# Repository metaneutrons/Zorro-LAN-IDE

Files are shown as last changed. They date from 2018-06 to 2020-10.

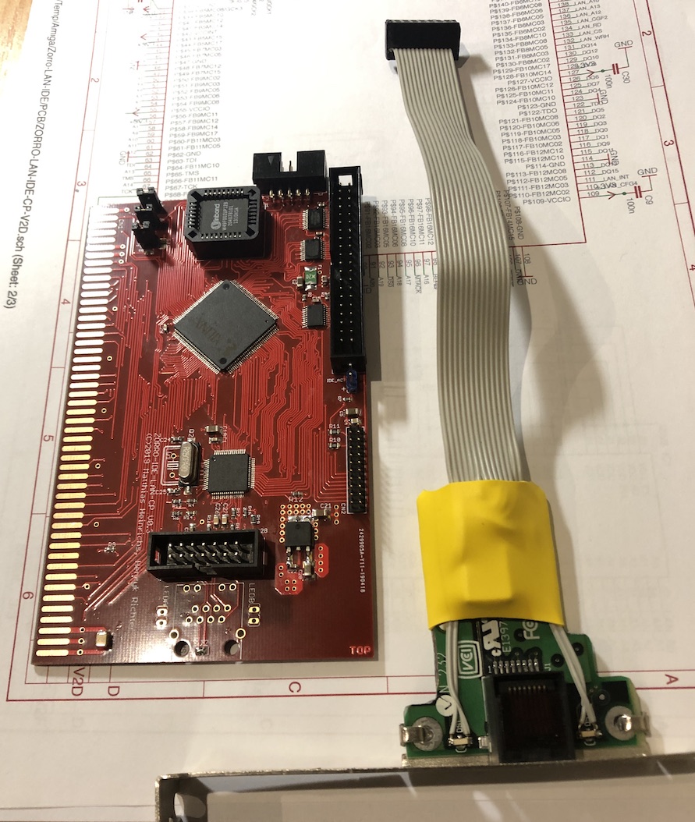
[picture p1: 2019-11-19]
Bilder/LANIDEv03.JPG

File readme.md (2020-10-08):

# Zorro-LAN-IDE
 
This is a Zorro-expansion card for the big Amigas (A2000/300/4000 or A500 with Zorro-interface). It has a SANAII-compatible Ethernet driver, an AT-BUS compatible IDE controller and a clockport for variuous expansions like a RapidRoard from Individual Computers.

Here is a pic of the first revision:
Zorro-Card with LAN-Module

All components are Autoconfig. The FastEthernet is based on a ENC624J600 lan chip. The clockport is compatible to A600/A1200 ones but resides at a different address. The IDE works from Kickstart 1.3 to 3.1.4 !

At present there are two firmwares: One for Zorro2, which runs in every Amiga with Zorro-Sots and one for A3000/4000, which puts the LAN-Chip into a Zorro3 environment. The while the Zorro2 variant can transfer 3.5mb/s at most the Zorro3-variant has a significantly faster LAN<->Amiga interface of 6-7mb/sec. Please note that these RAW data transfer numbers are not the only factor in LAN performance on Amiga and that the actual observed speeds with TCP transfers are in the range of 1-2 MB/s (depending on IP stack and CPU). 

Here is a pic of the current board revision:
Zorro-Card with onboard LAN chip

## Things to improve

* The second revision already adresses the issues of the Zorro3-incompatible IDE-Interface.
* There is no Z2/Z3 combo firmware, yet.
* The RJ45-breakout (actually it's a MagJack with build in transceiver) of the 2nd revision looks bad 

**DISCLAIMER!!!!**  
**THIS IS A HOBBYIST PROJECT! I'M NOT RESPONSIBLE IF IT DOESN'T WORK OR DESTROYS YOUR VALUABLE DATA!**

## License
All sources published under GNU GENERAL PUBLIC LICENSE V2.0

## Theory of operation
* This PCB has four layers and consists of a Xilinx XC95288XL, a bootrom and some bus bufferes for the IDE port, a clockport and a ENC624J600 including a RJ45-connector with integrated receiver. 

* The CPLD does four things:
    * It makes the Autoconfig for the IDE, the clockport and the LAN-chip
    * It adapts the LAN Chip to Zorro2/3 and does necessary byte swapping, so the Amiga can linearely access the whole chip.
    * It acesses the clockport
    * It controlls the IDE

## How to make the clockport work with a RapidRoad?

Make sure you connected the cable the right way! There is no "standarized way". So the easiest thing is to find out on the RapidRoad side on which row of the clockport the two outer pins are ground. These Pins mus run to the row of the Zorro-LAN-IDE-CP-card where the squared solder-hole is located. *Please triple check the cable with a multimeter! Wrong polarity of the cable can cause damage to your hardware!* 
Now you have to set up the driver to look for a clockport at the address of the expansion board. The address can be figured out by the system tool "ShowConfig" (Manufactor id: 2588 Product: 124). 
However, there is work on a software solution, that the RapidRoad finds itself automatically!

## What is in this repository?
This repository consists of several directories:

* Bilder: Some pictures of this project
* Doku: Some documentation and datasheets. Mainly for the ENC624J600
* Driver: Here is the driver developped by Henryk Richter
* Logic: Here the code, project files and pin-assignments for the CPLD is stored. There are two versions: 
* PCB: The board, schematic and bill of material (BOM) are in this directory. 
* root directory: the readme

## How to open the PCB-files?
You find the eagle board and schematic files (brd/sch) for the pcb. The software can be [downloaded](https://www.autodesk.com/products/eagle/overview) for free after registration. KiCad can import these files too. But importers are not 100% reliable... 

## How to make a PCB?
You can generate Gerber-files from the brd files according to the specs of your PCB-manufactor. Some specs: min trace width: 0.15mm/6mil, min trace dist: 0.15mm/6mil, min drill: 0.3mm

**ATTENTION: THE PCB has 4 layers!**

## How to get the parts?
Most parts can be found on digikey or mouser or a parts supplier of your choice.
A list of parts is found in the file [ZORRO-LAN-IDE-CP-V2E.txt](https://gitlab.com/MHeinrichs/Zorro-LAN-IDE/raw/master/PCB/ZORRO-LAN-IDE-CP-V2E.txt)

## How to programm the board?
The CPLD must be programmed via Xilinx IMPACT and an apropriate JTAG-dongle. The JED-File is provided. 

## It doesn't work! How to I get help?
For support visit the [a1k-forum](https://www.a1k.org/forum/showthread.php?t=56940). Yes, you need to register and it's German, but writing in English is accepted. For bug-reports write a ticket here ;).

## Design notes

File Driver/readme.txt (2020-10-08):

These are the AmigaOS drivers for the subsystems of the board.

The recommended SANA-II driver for the Ethernet port is located in "baxnet". 

Please use enc624j6net.device from baxnet/bin on MC68020 or faster CPUs. A cut-down version for 68000 and 68010 is provided as well. Please rename enc624j6net.device_68000 to enc624j6net.device before copying it to DEVS:Networks.

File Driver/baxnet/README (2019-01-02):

Short:        V2.00, SANA-II network drivers for several adapters 
Author:       Henryk Richter
Uploader:     henryk.richter@gmx.net
Type:         driver/net
Architecture: m68k-amigaos
Requires:     OS 2.04+

This package contains network drivers for the following hardware:
- ZII LAN IDE CP (matze, scrat and buggs @a1k.org)
  OSS Zorro-II card with ENC624J600 ethernet controller, autoboot
  IDE and Clockport
- Vampire500/600 with ENC28J60 module connected to the SD-card slot
- Vampire500V2+ with ENC28J60 module connected to the expansion port

Full source code is included. Please refer to README.sdnet and
README.enc for installation and operation instructions

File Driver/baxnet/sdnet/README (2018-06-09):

SDNet - A SANA-II driver for ENC28J60 10BaseT ethernet modules

Written in 2016-2018 by Henryk Richter <henryk.richter@gmx.net>

This driver is supposed to support ENC28J60 modules hooked up to the MicroSD
slot of Vampire 500/600 cards or the expansion port of Vampire 500V2+ cards.

Installation:
-------------

Installation of the driver is straightforward. 
Just copy the sdnet.device and v2expeth.device to devs:networks and enable 
the interface in your favorite  TCP/IP stack as usual. So far, successful 
tests have been done with the free AmiTCP/IP 3.0b2, AmiTCP4.0-4.2, Genesis, 
MiamiDX and RoadShow. 

devs:networks/sdnet.device    - SD card slot of V600/V500
devs:networks/v2expeth.device - expansion port of V500V2+

From version 0.8, the driver will require vampire.resource which is included
in the ROM of Vampire Cards since the Gold2.5 release.

Also, make sure that the Vampire SD Card driver (sagasd.device) is not present
in the system or at least inactive when using sdnet.device. Both pieces of 
software bang the same hardware registers. v2expeth.device may be used safely
in conjunction with the SD card driver.

Vampire500 Expansion port Hardware
-----------------------------------

Please see http://wiki.apollo-accelerators.com/doku.php/expansionport for 
guidance.

MicroSD Slot Hardware:
----------------------

In terms of required hardware, you need the following:
- ready-to-use ENC28J60 module (a 3.3V part, DON'T USE an _unmodified_ 5V 
  module!)
- MicroSD breakout, e.g.
  - a TF to SD extension cable where you rip off the full size SD slot and 
    solder on short extension cables towards the ENC28J60 module
  - MicroSD breakout board (that comes directly with pin headers)

!!ATTENTION!!
Be extremely careful with your SD breakout board. Many conveniently looking
breakouts are made of thick and/or sharp edged PCB material that will likely
damage your Vampire SD slot. Such breakouts could be made working - but only 
after  patient sanding. Some people in the beta test team have destroyed 
their SD  slot already. If you don't have the required mechanical skills and 
patience, I'd advise against DIY building.
!!ATTENTION!!

You need to connect the SD breakout pins as follows (microSD card sketch
looking at the connectors) to the ENC28J60 module:

 -----------------------                       ENC28J60
 |  8  ----
 |  7  ----           SO  --------------------  SO
 |  6 -----          GND  --------------------  GND
 |  5  ----          SCK  --------------------  SCK
 |  4 -----        +3.3V  ------  +3.3V  -----  VCC (see below)
 |  3  ----           SI  --------------------  SI
 |  2  ----          /CS  --------------------  /CS
 |  1  ----         /INT  --   __________   -- /INT
 ------    -------------    \_| 3.3 kOhm |_/
       \___|                  `----------´

As there is a myriad of ENC28J60 modules available, the naming scheme on
a particular board might differ. Please be aware the some of the boards
have a "CLK" pin as well as an "SCK" pin. Use the latter. 

My test setup uses a separate 5V to 3.3V DC-DC converter. I got confirmation 
from Igor Majstorovic (majsta) that the 3.3V line on his V500 Vampire designs 
should be able to handle the max. 200 mA required by the module. To be on the 
safe side, I recommend to use a conveniently placed 5V to 3.3V converter 
(hint: the Floppy power connector is easily accessible). 

Speaking of power: the reason why I didn't recommend 5V ENC28J60 boards 
is that at least some of them have pullups from /CS and /RST to +5V. Your 3.3V
Vampire SD slot will quite likely not be happy with that.

Please put a 3.3 kOhm resistor into the connection from /INT of the ENC28J60 to
pin 1 of the MicroSD breakout.

Testing a new module:
---------------------

I've included two small test programs: sdnettest and v2expethtest. Both will 
require the TCP/IP stack to be off(!) The program will perform a series of tests 
to check for module presence and communication results at various clock rates. Don't 
be alarmed when the slowest (biggest clock divider) mode is commented with a "fail". 
This is intentional. What matters is that SPI clock dividers 1, 2 and 3 are working 
properly. In case that sdnettest shows a failure for divider 1, see below how
to set a higher clock divider.

Use sdnettest for the SD slot and v2expethtest for the V500 expansion connector.

Software notes:
---------------

 - The SD slot doesn't feature an interrupt. I had to implement polling
   for incoming data. The current default interval is 10ms. (configurable via
   echo "TIMER=20000" >ENVARC:sana2/sdnet.config, value in microseconds,
   don't forget Makedir ENVARC:Sana2 if it didn't exist yet, you may also
   consider "setenv")

 - SPI speed is set to a safe level supporting higher core speeds than
   x11 (see released x12 cores). Therefore this default of "SPISPEED=2"
   is not providing maximum performance on x10 or x11 cores. For max
   speed you may set echo "SPISPEED=1" >ENVARC:sana2/sdnet.config or
   echo "SPISPEED=1" >ENVARC:sana2/v2expeth.config, respectively. I'd
   suggest to run the test tool to determine the maximum reliable
   speed setting.

 - The required vampire.resource is unavailable with older versions of the
   Vampire Kick Rom (anything before Gold2.5). 
   To load vampire.resource manually, copy the file to SYS:devs/ and 
   add the following near the top of your startup-sequence
    C:VERSION >nil: vampire.resource 42
    IF WARN
       LoadModule >nil: DEVS:vampire.resource
    ENDIF
   In case of OS3.9, you can add the "noreboot" keyword to the loadmodule
   line if you call the sniplet above before setpatch.

 - If you want to use multiple options in the SANA-II config, concatenate them 
   in the "echo" command (alternatively "setenv") or use a text editor. 

Options 
-------

Below you find the options accepted by the drivers. Please note that no special
configuration is necessary for normal operation. What you find documented below
is available for tuning purposes.

The options template for the config files 
ENVARC:sana2/sdnet.config  
ENVARC:sana2/v2expeth.config

is as follows:

NOSPECIALSTATS/S,PRIORITY=PRI/K/N,BPS/K/N,MTU/K/N,FULLDUPLEX/S,SPISPEED/K/N,
TIMER/K/N,MULTICAST/S

 SPISPEED       - SPI clock divider (1-10, default 2), controls maximum
                  clock of SPI bus. Actual I/O clock is Core_Clock/(3+SPISPEED).

 FULLDUPLEX     - change Ethernet module into full duplex mode, 
                  caution: requires manual configuration of duplex mode
		           on the switch, too.

 PRIORITY       - server task priority (default 1)

 BPS            - bit per seconds for statistics purposes

 MTU            - maximum transmission unit (default 1500) 

 NOSPECIALSTATS - obsolete, kept for config file backwards compatibility with 
                  old driver

 MULTICAST      - obsolete, kept for config file backwards compatibility with 
                  old driver

 example (useful for DSL via PPPoE on x11 core with AmiTCP):
  echo "MTU=1492 SPISPEED=1 PRIORITY=6" >ENVARC:sana2/sdnet.config  

Changelog:
----------

1.90  - first Beta of completely rewritten driver
      - support for concurrent IP stacks
      - faster handling of statistics
      - multiple board support where applicable (not for sdnet)
      - workaround for Shapeshifter network plugin bug
      - GCC or VBCC as compiler
      - faster lowlevel read/write

1.03  - small fixes in sdnettest/v2expethtest, graceful exit when not run
        on Vampire Gold 2.5 or later core
      - fixed a minor bug in signal handling

1.02  - added build variant for V500V2+ expansion port, same config options
        but distinct config file (ENV:SANA2/v2expeth.config), see
	http://wiki.apollo-accelerators.com/doku.php/expansionport for pinout
      - some more work on robustness (TX robustness and more error handling
        this time)
      - reworked test utilities to send valid BOOTP/DHCP requests while
        doing TX/RX testing, increases chance of received frames within
	testing interval

1.01  - some more fine tuning
      - adjustments for Gold 2.7 x12, i.e. SPISPEED=2 by default 
        (see above for reverting to clock divider 1)

1.0   - some modest performance improvements
      - reworked lowlevel code for higher robustness
      - LED blinking modified: green LED will blink on RX,
        orange LED blinks on TX

0.81  - sdnettest added

0.8   - proper hardware allocation by means of vampire.resource
      - check for ENC28J60 hardware presence

0.7   - cleanups

0.6   - SPI speed setting support
      - removal of spi.c,spi.h

0.5   - auto-generated MAC address, based on the Vampire FPGA serial
      - busy waiting moved entirely to lowlevel asm source
      - optimized compilation now produces working binaries
      - more cleanups

0.4   - cleanups, config variables added

0.3   - first version shared with the Apollo team

Copyrights:
-----------

The SDNet source is heavily based on plipbox, which is in turn based on the magPLIP 
driver found on aminet.net:

http://lallafa.de/blog/amiga-projects/plipbox/
http://aminet.net/package/comm/net/magPLIP38.1

magPLIP - SANA II compliant PLIP device driver for AmiTCP/IP, Envoy,
	    AS225 and other networking packages

  (C) Copyright 1993-1994 Oliver Wagner, Michael Balzer
  (C) Copyright 1995 Jan Kratochvil & Martin Mares
  (C) Copyright 1995-1996 Marius Groeger
      All Rights Reserved.

  Changes have been made by Stéphane Zermatten to the driver to connect
  a LinuxBox to an Amiga via a LapLing cable, based on the release 37.8.

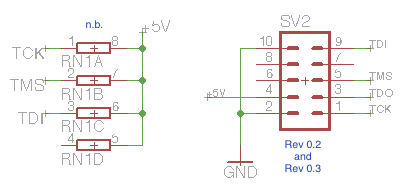
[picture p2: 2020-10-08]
Bilder/JTAG_BoardRev02.png

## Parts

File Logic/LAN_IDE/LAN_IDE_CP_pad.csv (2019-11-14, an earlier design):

Release 8.1i - Fit P.20131013
Copyright(c) 1995-2003 Xilinx Inc. All rights reserved
5-22-2019 11:50PM
NOTE: This file is designed to be imported into a spreadsheet program
such as Microsoft Excel for viewing | printing and sorting. The comma ' | '
character is used as the data field separator.
This file is also designed to support parsing.
Input file: LAN_IDE_CP.ngd
output file: LAN_IDE_CP_pad.csv
Part type: xc95288xl
Speed grade: -10
Package: tq144
Pinout by Pin Number:
----- | ----- | ----- | ----- | ----- | ----- | ----- | ----- | ----- | -----
Pin Number | Signal Name | Pin Usage | Pin Name | Direction | IO Standard | IO Bank Number | {blank} | Slew Rate | Termination | {blank} | Voltage | Constraint
P1 | VCC |  | VCCIO
P2 | D<0> | I/O | I/O/GTS3 | BIDIR
P3 | A_LAN<1> | O | I/O/GTS4 | OUTPUT
P4 | A_LAN<0> | O | I/O | OUTPUT
P5 | A_LAN<3> | O | I/O/GTS1 | OUTPUT
P6 | A_LAN<2> | O | I/O/GTS2 | OUTPUT
P7 | A_LAN<5> | O | I/O | OUTPUT
P8 | VCC |  | VCCINT
P9 | A_LAN<4> | O | I/O | OUTPUT
P10 | A_LAN<7> | O | I/O | OUTPUT
P11 | A_LAN<6> | O | I/O | OUTPUT
P12 | LAN_CFG<1> | O | I/O | OUTPUT
P13 | LAN_CFG<3> | O | I/O | OUTPUT
P14 | D<6> | I/O | I/O | BIDIR
P15 | D<3> | I/O | I/O | BIDIR
P16 | D<7> | I/O | I/O | BIDIR
P17 | D<1> | I/O | I/O | BIDIR
P18 | GND |  | GND
P19 | D<8> | I/O | I/O | BIDIR
P20 | D<5> | I/O | I/O | BIDIR
P21 | D<4> | I/O | I/O | BIDIR
P22 | IDE_CS<0> | O | I/O | OUTPUT
P23 | IDE_CS<1> | O | I/O | OUTPUT
P24 | IDE_A<0> | O | I/O | OUTPUT
P25 | IDE_A<2> | O | I/O | OUTPUT
P26 | IDE_A<1> | O | I/O | OUTPUT
P27 | IDE_R | O | I/O | OUTPUT
P28 | IDE_W | O | I/O | OUTPUT
P29 | GND |  | GND
P30 | CLK_EXT | GCK | I/O/GCK1
P31 | CP_IRQ | I | I/O | INPUT
P32 | INT2_OUT | O | I/O/GCK2 | OUTPUT
P33 | ROM_B<0> | O | I/O | OUTPUT
P34 | CP_CS | O | I/O | OUTPUT
P35 | ROM_OE | O | I/O | OUTPUT
P36 | GND |  | GND
P37 | VCC |  | VCCIO
P38 | TIE |  | I/O/GCK3
P39 | D<2> | I/O | I/O | BIDIR
P40 | D<9> | I/O | I/O | BIDIR
P41 | D<10> | I/O | I/O | BIDIR
P42 | VCC |  | VCCINT
P43 | D<11> | I/O | I/O | BIDIR
P44 | D<12> | I/O | I/O | BIDIR
P45 | D<13> | I/O | I/O | BIDIR
P46 | D<14> | I/O | I/O | BIDIR
P47 | GND |  | GND
P48 | D<15> | I/O | I/O | BIDIR
P49 | A<5> | I | I/O | INPUT
P50 | A<4> | I | I/O | INPUT
P51 | A<6> | I | I/O | INPUT
P52 | A<3> | I | I/O | INPUT
P53 | A<7> | I | I/O | INPUT
P54 | A<2> | I | I/O | INPUT
P55 | VCC |  | VCCIO
P56 | A<8> | I/O | I/O | BIDIR
P57 | A<1> | I | I/O | INPUT
P58 | A<9> | I/O | I/O | BIDIR
P59 | A<10> | I/O | I/O | BIDIR
P60 | A<11> | I/O | I/O | BIDIR
P61 | A<12> | I/O | I/O | BIDIR
P62 | GND |  | GND
P63 | TDI |  | TDI
P64 | A<13> | I/O | I/O | BIDIR
P65 | TMS |  | TMS
P66 | A<14> | I/O | I/O | BIDIR
P67 | TCK |  | TCK
P68 | INT6_OUT | O | I/O | OUTPUT
P69 | ROM_B<1> | O | I/O | OUTPUT
P70 | CP_WE | O | I/O | OUTPUT
P71 | CP_RD | O | I/O | OUTPUT
P72 | GND |  | GND
P73 | VCC |  | VCCIO
P74 | A<15> | I/O | I/O | BIDIR
P75 | AUTOBOOT_OFF | I | I/O | INPUT
P76 | LAN_WRL | O | I/O | OUTPUT
P77 | FCS | I | I/O | INPUT
P78 | DS1 | I | I/O | INPUT
P79 | Z3 | I | I/O | INPUT
P80 | AS | I | I/O | INPUT
P81 | UDS | I | I/O | INPUT
P82 | LDS | I | I/O | INPUT
P83 | RW | I | I/O | INPUT
P84 | VCC |  | VCCINT
P85 | DTACK | O | I/O | OUTPUT
P86 | A<23> | I/O | I/O | BIDIR
P87 | A<22> | I/O | I/O | BIDIR
P88 | A<21> | I/O | I/O | BIDIR
P89 | GND |  | GND
P90 | GND |  | GND
P91 | A<20> | I/O | I/O | BIDIR
P92 | A<19> | I/O | I/O | BIDIR
P93 | DS0 | I | I/O | INPUT
P94 | A<18> | I/O | I/O | BIDIR
P95 | A<17> | I/O | I/O | BIDIR
P96 | MTACK | O | I/O | OUTPUT
P97 | A<16> | I/O | I/O | BIDIR
P98 | TIE |  | I/O
P99 | GND |  | GND
P100 | OVR | O | I/O | OUTPUT
P101 | MTCR | I | I/O | INPUT
P102 | C3 | I | I/O | INPUT
P103 | C1 | I | I/O | INPUT
P104 | CFIN | I | I/O | INPUT
P105 | CFOUT | O | I/O | OUTPUT
P106 | SLAVE | O | I/O | OUTPUT
P107 | OWN | O | I/O | OUTPUT
P108 | GND |  | GND
P109 | VCC |  | VCCIO
P110 | LAN_CFG<4> | O | I/O | OUTPUT
P111 | LAN_INT | I | I/O | INPUT
P112 | DQ<15> | I/O | I/O | BIDIR
P113 | DQ<13> | I/O | I/O | BIDIR
P114 | GND |  | GND
P115 | DQ<11> | I/O | I/O | BIDIR
P116 | DQ<9> | I/O | I/O | BIDIR
P117 | DQ<1> | I/O | I/O | BIDIR
P118 | DQ<0> | I/O | I/O | BIDIR
P119 | DQ<3> | I/O | I/O | BIDIR
P120 | DQ<2> | I/O | I/O | BIDIR
P121 | DQ<5> | I/O | I/O | BIDIR
P122 | TDO |  | TDO
P123 | GND |  | GND
P124 | DQ<4> | I/O | I/O | BIDIR
P125 | DQ<7> | I/O | I/O | BIDIR
P126 | DQ<6> | I/O | I/O | BIDIR
P127 | VCC |  | VCCIO
P128 | DQ<8> | I/O | I/O | BIDIR
P129 | DQ<10> | I/O | I/O | BIDIR
P130 | DQ<12> | I/O | I/O | BIDIR
P131 | DQ<14> | I/O | I/O | BIDIR
P132 | LAN_WRH | O | I/O | OUTPUT
P133 | LAN_CS | O | I/O | OUTPUT
P134 | LAN_RD | O | I/O | OUTPUT
P135 | LAN_CFG<2> | O | I/O | OUTPUT
P136 | A_LAN<12> | O | I/O | OUTPUT
P137 | A_LAN<13> | O | I/O | OUTPUT
P138 | A_LAN<10> | O | I/O | OUTPUT
P139 | A_LAN<11> | O | I/O | OUTPUT
P140 | A_LAN<8> | O | I/O | OUTPUT
P141 | VCC |  | VCCINT
P142 | A_LAN<9> | O | I/O | OUTPUT
P143 | RESET | I | I/O/GSR | INPUT
P144 | GND |  | GND
To preserve the pinout above for future design iterations in
Project Navigator simply execute the (Lock Pins) process
located under the (Implement Design) process in a toolbox named
(Optional Implementation Tools) or invoke PIN2UCF from the
command line. The location constraints will be written into your
specified UCF file

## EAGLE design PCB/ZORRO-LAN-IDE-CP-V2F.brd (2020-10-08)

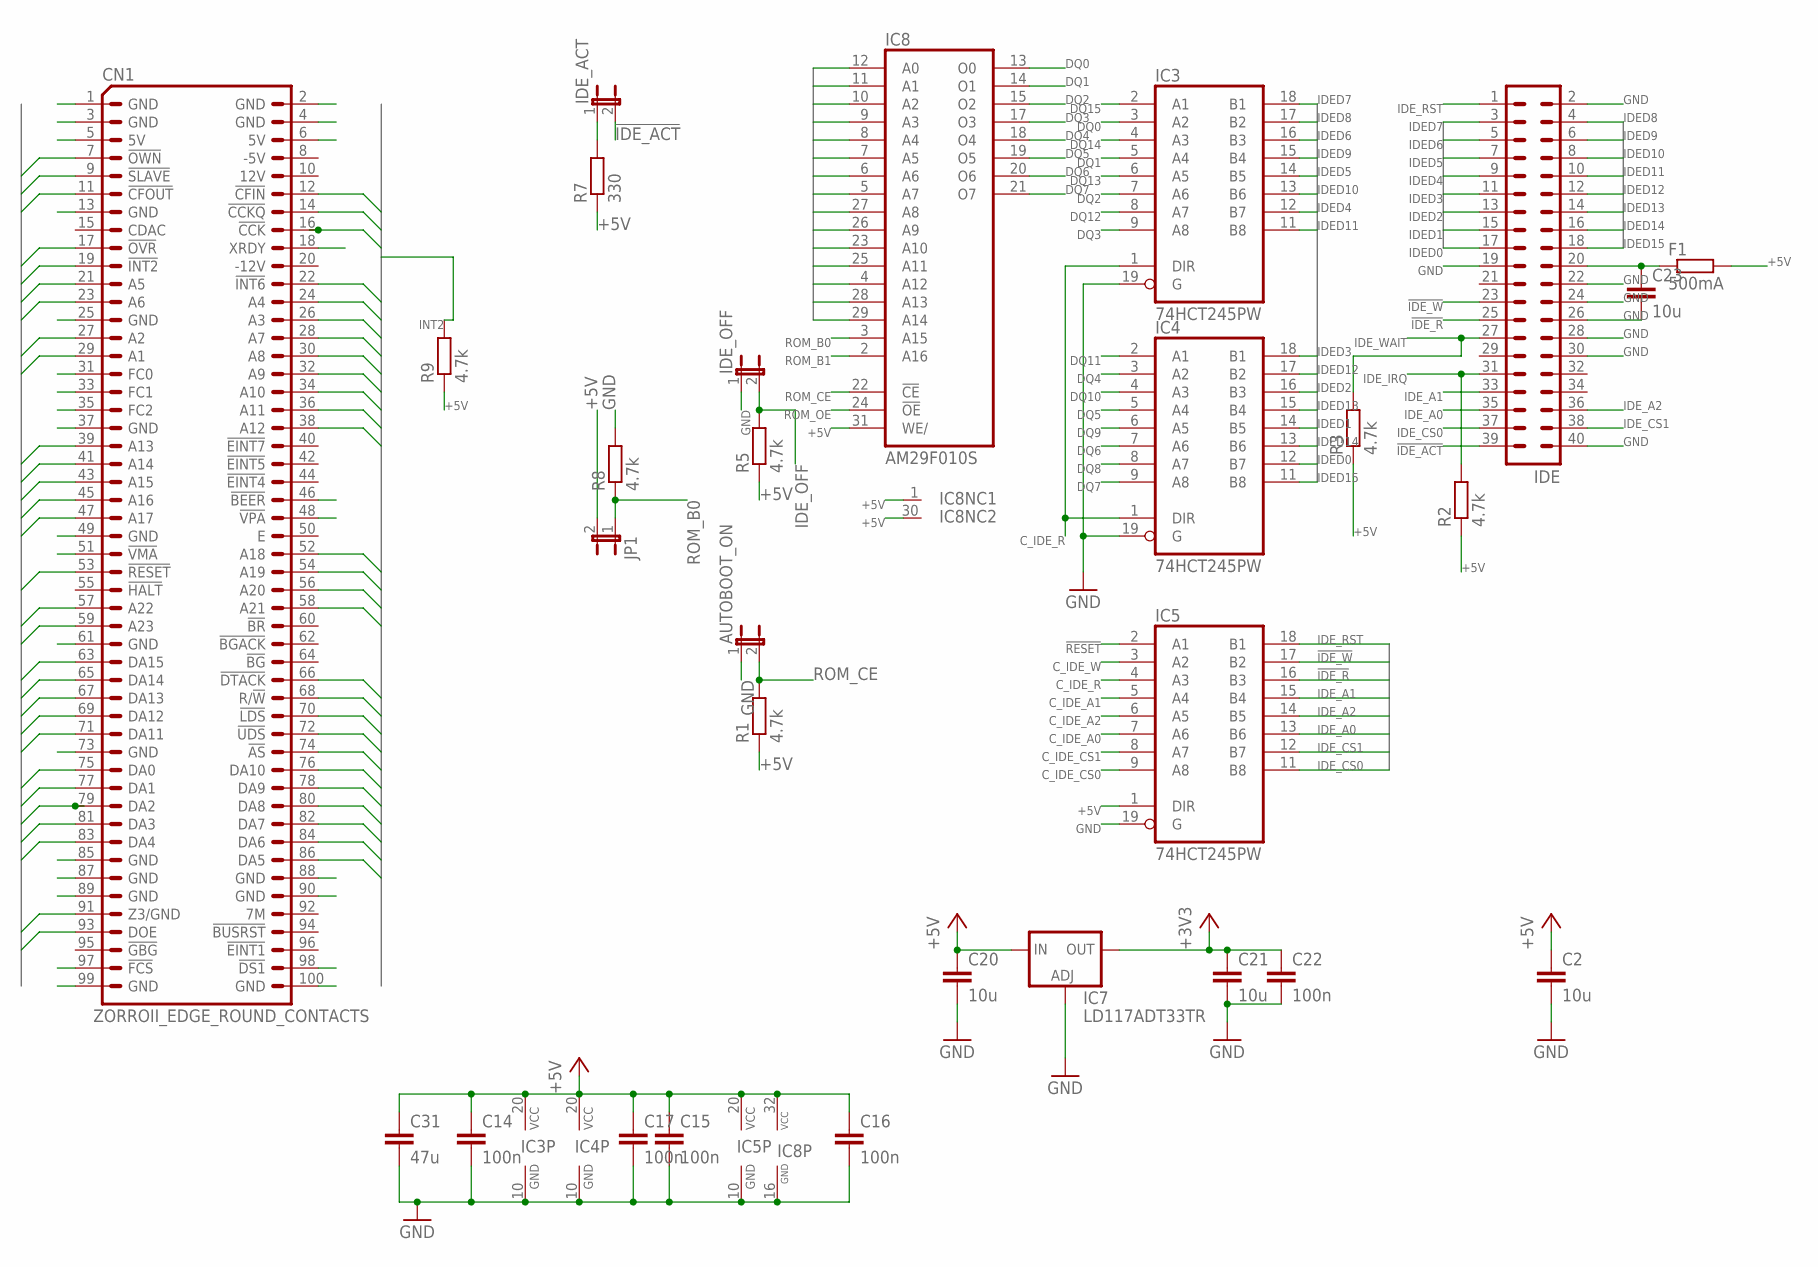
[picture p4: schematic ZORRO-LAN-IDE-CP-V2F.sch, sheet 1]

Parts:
AUTOBOOT_ON: JP1E; JP1
C2, C23: 10u; C0805K
C14, C15, C16, C17, C22: 100n; C0603K
C20: 10u; C1206K
C21: 10u; C1210K
C31: 47u; C1206K
CN1: ZORROII_EDGE_ROUND_CONTACTS; LKONT_50_R
F1: 500mA; R2512
IC3, IC4, IC5: 74HCT245PW; TSSOP20
IC7: LD117ADT33TR; DPACK
IC8: AM29F010S; PLCC-SR32
IDE: ML40
IDE_ACT: JP1E; JP1
IDE_OFF: JP1E; JP1
JP1: JP1E; JP1
R1, R2, R3, R5, R8, R9: 4.7k; R0603
R7: 330; R0603

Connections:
!AS: CN1.74 (!AS!); also elsewhere on the board
!BERR: CN1.46 (!BEER!); also elsewhere on the board
!CFIN: CN1.12 (!CFIN!); also elsewhere on the board
!CFOUT: CN1.11 (!CFOUT!); also elsewhere on the board
!DS0: CN1.51 (!VMA!); also elsewhere on the board
!DS1: CN1.98 (!DS1!); also elsewhere on the board
!DTACK: CN1.66 (!DTACK!); also elsewhere on the board
!FCS: CN1.97 (!FCS!); also elsewhere on the board
!IDE_ACT: IDE.39, IDE_ACT.2
!IDE_R: IC5.16 (B3), IDE.25
!IDE_W: IC5.17 (B2), IDE.23
!LDS: CN1.70 (!LDS!); also elsewhere on the board
!MTACK: CN1.48 (!VPA!); also elsewhere on the board
!MTCR: CN1.18 (XRDY); also elsewhere on the board
!OVR: CN1.17 (!OVR!); also elsewhere on the board
!OWN: CN1.7 (!OWN!); also elsewhere on the board
!RESET: CN1.53 (!RESET!), IC5.2 (A1); also elsewhere on the board
!SLAVE: CN1.9 (!SLAVE!); also elsewhere on the board
!UDS: CN1.72 (!UDS!); also elsewhere on the board
+3V3: C21.1, C22.1, IC7.4 (OUT); also elsewhere on the board
+5V: C2.1, C14.1, C15.1, C16.1, C17.1, C20.1, C31.1, CN1.5 (5V), CN1.6 (5V), F1.2, IC3.20 (VCC), IC4.20 (VCC), IC5.1 (DIR), IC5.20 (VCC), IC7.3 (IN), IC8.1 (NC), IC8.30 (NC), IC8.31 (WE/), IC8.32 (VCC), JP1.2, R1.1, R2.1, R3.1, R5.1, R7.1, R9.1; also elsewhere on the board
A1: CN1.29 (A1), IC8.12 (A0); also elsewhere on the board
A2: CN1.27 (A2), IC8.11 (A1); also elsewhere on the board
A3: CN1.26 (A3), IC8.10 (A2); also elsewhere on the board
A4: CN1.24 (A4), IC8.9 (A3); also elsewhere on the board
A5: CN1.21 (A5), IC8.8 (A4); also elsewhere on the board
A6: CN1.23 (A6), IC8.7 (A5); also elsewhere on the board
A7: CN1.28 (A7), IC8.6 (A6); also elsewhere on the board
A8: CN1.30 (A8), IC8.5 (A7); also elsewhere on the board
A9: CN1.32 (A9), IC8.27 (A8); also elsewhere on the board
A10: CN1.34 (A10), IC8.26 (A9); also elsewhere on the board
A11: CN1.36 (A11), IC8.23 (A10); also elsewhere on the board
A12: CN1.38 (A12), IC8.25 (A11); also elsewhere on the board
A13: CN1.39 (A13), IC8.4 (A12); also elsewhere on the board
A14: CN1.41 (A14), IC8.28 (A13); also elsewhere on the board
A15: CN1.43 (A15), IC8.29 (A14); also elsewhere on the board
A16: CN1.45 (A16); also elsewhere on the board
A17: CN1.47 (A17); also elsewhere on the board
A18: CN1.52 (A18); also elsewhere on the board
A19: CN1.54 (A19); also elsewhere on the board
A20: CN1.56 (A20); also elsewhere on the board
A21: CN1.58 (A21); also elsewhere on the board
A22: CN1.57 (A22); also elsewhere on the board
A23: CN1.59 (A23); also elsewhere on the board
C1: CN1.14 (!CCKQ!); also elsewhere on the board
C3: CN1.16 (!CCK!); also elsewhere on the board
C_IDE_A0: IC5.7 (A6); also elsewhere on the board
C_IDE_A1: IC5.5 (A4); also elsewhere on the board
C_IDE_A2: IC5.6 (A5); also elsewhere on the board
C_IDE_CS0: IC5.9 (A8); also elsewhere on the board
C_IDE_CS1: IC5.8 (A7); also elsewhere on the board
C_IDE_R: IC3.1 (DIR), IC4.1 (DIR), IC5.4 (A3); also elsewhere on the board
C_IDE_W: IC5.3 (A2); also elsewhere on the board
D0: CN1.75 (DA0); also elsewhere on the board
D1: CN1.77 (DA1); also elsewhere on the board
D2: CN1.79 (DA2); also elsewhere on the board
D3: CN1.81 (DA3); also elsewhere on the board
D4: CN1.83 (DA4); also elsewhere on the board
D5: CN1.86 (DA5); also elsewhere on the board
D6: CN1.84 (DA6); also elsewhere on the board
D7: CN1.82 (DA7); also elsewhere on the board
D8: CN1.80 (DA8); also elsewhere on the board
D9: CN1.78 (DA9); also elsewhere on the board
D10: CN1.76 (DA10); also elsewhere on the board
D11: CN1.71 (DA11); also elsewhere on the board
D12: CN1.69 (DA12); also elsewhere on the board
D13: CN1.67 (DA13); also elsewhere on the board
D14: CN1.65 (DA14); also elsewhere on the board
D15: CN1.63 (DA15); also elsewhere on the board
DOE: CN1.93 (DOE); also elsewhere on the board
DQ0: IC3.3 (A2), IC8.13 (O0); also elsewhere on the board
DQ1: IC3.5 (A4), IC8.14 (O1); also elsewhere on the board
DQ2: IC3.7 (A6), IC8.15 (O2); also elsewhere on the board
DQ3: IC3.9 (A8), IC8.17 (O3); also elsewhere on the board
DQ4: IC4.3 (A2), IC8.18 (O4); also elsewhere on the board
DQ5: IC4.5 (A4), IC8.19 (O5); also elsewhere on the board
DQ6: IC4.7 (A6), IC8.20 (O6); also elsewhere on the board
DQ7: IC4.9 (A8), IC8.21 (O7); also elsewhere on the board
DQ8: IC4.8 (A7); also elsewhere on the board
DQ9: IC4.6 (A5); also elsewhere on the board
DQ10: IC4.4 (A3); also elsewhere on the board
DQ11: IC4.2 (A1); also elsewhere on the board
DQ12: IC3.8 (A7); also elsewhere on the board
DQ13: IC3.6 (A5); also elsewhere on the board
DQ14: IC3.4 (A3); also elsewhere on the board
DQ15: IC3.2 (A1); also elsewhere on the board
FC0: CN1.31 (FC0)
FC1: CN1.33 (FC1)
FC2: CN1.35 (FC2)
GND: AUTOBOOT_ON.1, C2.2, C14.2, C15.2, C16.2, C17.2, C20.2, C21.2, C22.2, C23.2, C31.2, CN1.1 (GND), CN1.2 (GND), CN1.3 (GND), CN1.4 (GND), CN1.13 (GND), CN1.25 (GND), CN1.37 (GND), CN1.49 (GND), CN1.61 (GND), CN1.73 (GND), CN1.85 (GND), CN1.87 (GND), CN1.88 (GND), CN1.89 (GND), CN1.90 (GND), CN1.99 (GND), CN1.100 (GND), IC3.10 (GND), IC3.19 (G), IC4.10 (GND), IC4.19 (G), IC5.10 (GND), IC5.19 (G), IC7.1 (ADJ), IC8.16 (GND), IDE.2, IDE.19, IDE.22, IDE.24, IDE.26, IDE.28, IDE.30, IDE.40, IDE_OFF.1, R8.2; also elsewhere on the board
IDED0: IC4.12 (B7), IDE.17
IDED1: IC4.14 (B5), IDE.15
IDED2: IC4.16 (B3), IDE.13
IDED3: IC4.18 (B1), IDE.11
IDED4: IC3.12 (B7), IDE.9
IDED5: IC3.14 (B5), IDE.7
IDED6: IC3.16 (B3), IDE.5
IDED7: IC3.18 (B1), IDE.3
IDED8: IC3.17 (B2), IDE.4
IDED9: IC3.15 (B4), IDE.6
IDED10: IC3.13 (B6), IDE.8
IDED11: IC3.11 (B8), IDE.10
IDED12: IC4.17 (B2), IDE.12
IDED13: IC4.15 (B4), IDE.14
IDED14: IC4.13 (B6), IDE.16
IDED15: IC4.11 (B8), IDE.18
IDE_A0: IC5.13 (B6), IDE.35
IDE_A1: IC5.15 (B4), IDE.33
IDE_A2: IC5.14 (B5), IDE.36
IDE_CS0: IC5.11 (B8), IDE.37
IDE_CS1: IC5.12 (B7), IDE.38
IDE_IRQ: IDE.31, R2.2
IDE_OFF: IDE_OFF.2, R5.2; also elsewhere on the board
IDE_RST: IC5.18 (B1), IDE.1; also elsewhere on the board
IDE_WAIT: IDE.27, R3.2; also elsewhere on the board
INT2: CN1.19 (!INT2!), R9.2; also elsewhere on the board
INT6: CN1.22 (!INT6!); also elsewhere on the board
KEY_PIN_POWER: C23.1, F1.1, IDE.20
unnamed: IDE_ACT.1, R7.2
R/W: CN1.68 (R/!W!); also elsewhere on the board
ROM_B0: IC8.3 (A15), JP1.1, R8.1; also elsewhere on the board
ROM_B1: IC8.2 (A16); also elsewhere on the board
ROM_CE: AUTOBOOT_ON.2, IC8.22 (!CE), R1.2
ROM_OE: IC8.24 (!OE); also elsewhere on the board
Z3: CN1.91 (Z3/GND); also elsewhere on the board

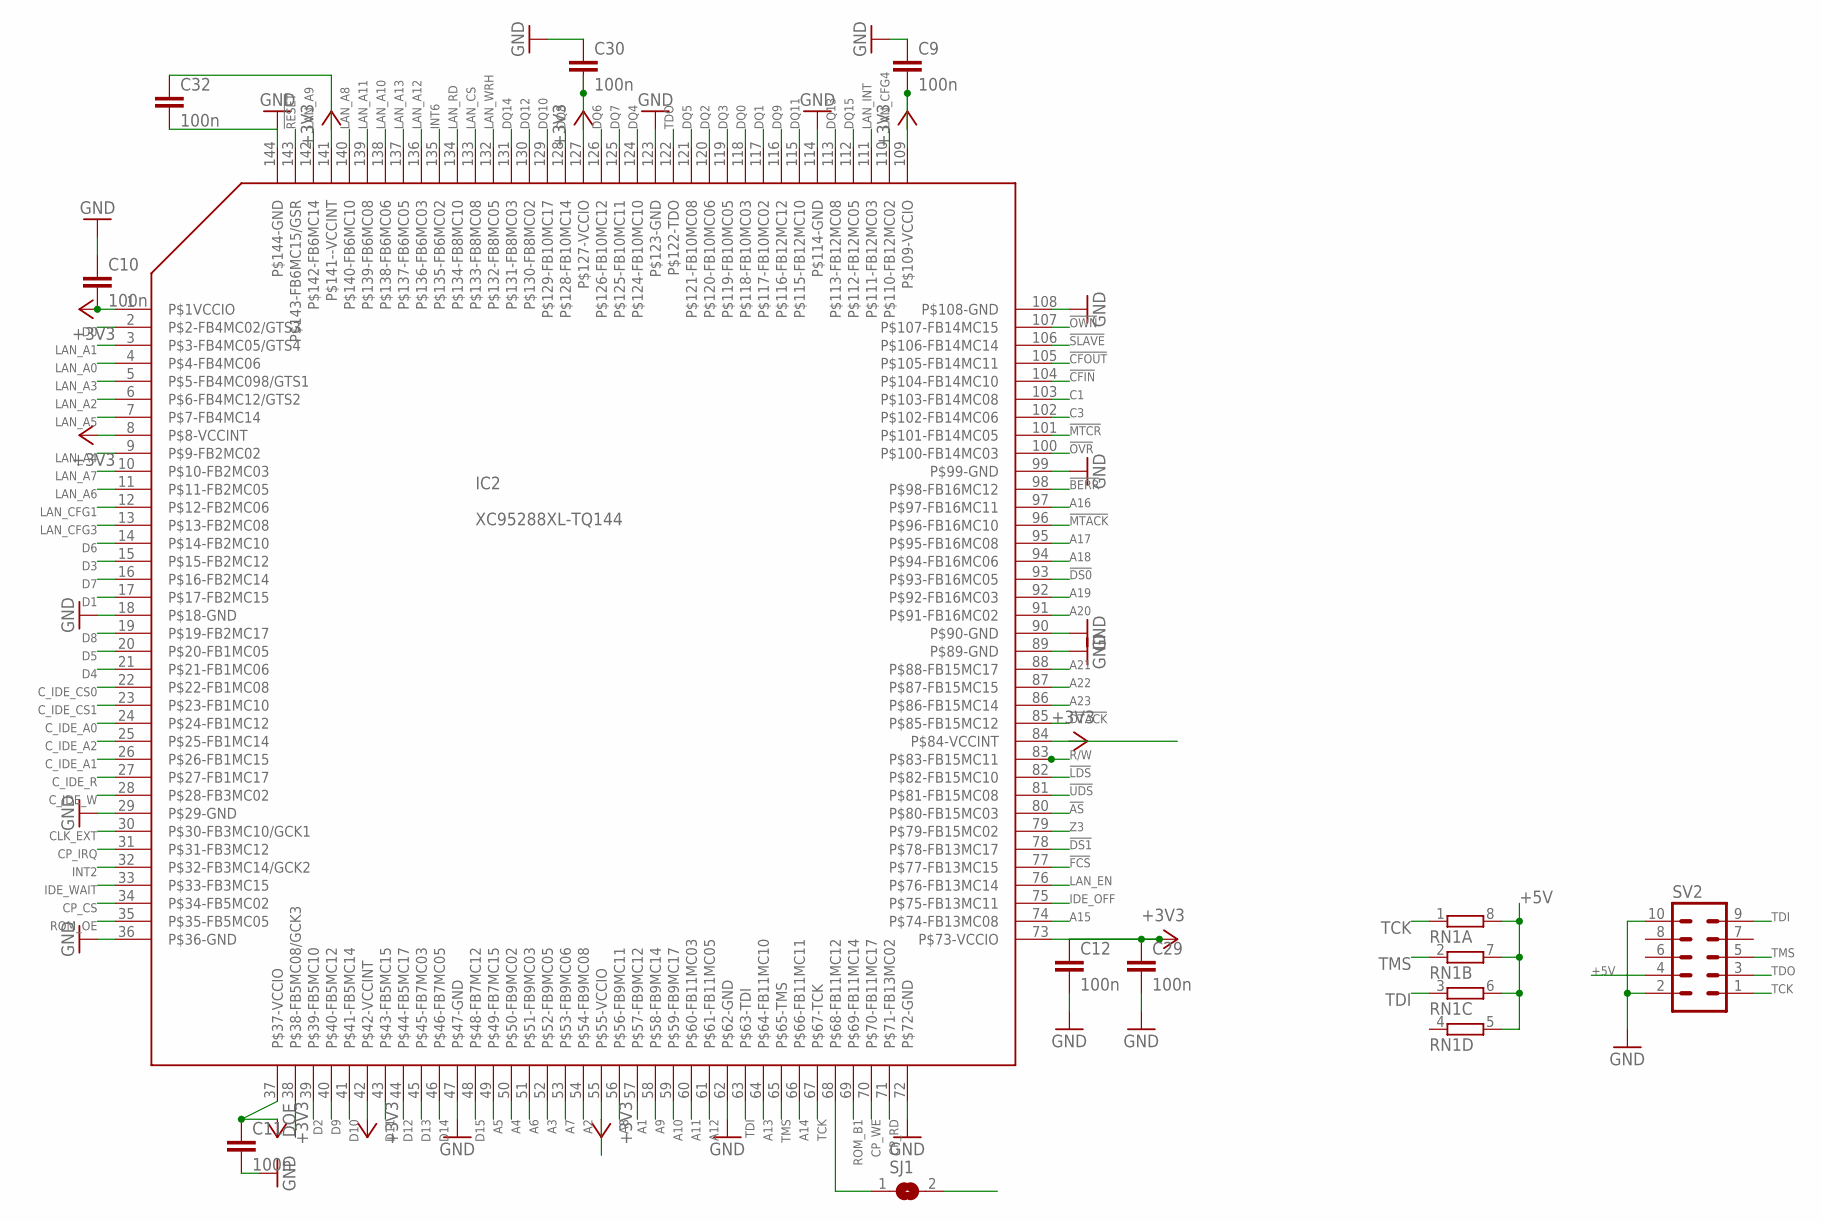
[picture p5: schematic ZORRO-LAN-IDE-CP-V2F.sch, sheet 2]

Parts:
C9, C10, C11, C12, C29, C30, C32: 100n; C0603K
IC2: XC95288XL-TQ144; TQFP144
RN1: 4R-NCAY16; CAY16
SJ1: SJ
SV2: ML10L

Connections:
!AS: IC2.80 (P$80-FB15MC03); also elsewhere on the board
!BERR: IC2.98 (P$98-FB16MC12); also elsewhere on the board
!CFIN: IC2.104 (P$104-FB14MC10); also elsewhere on the board
!CFOUT: IC2.105 (P$105-FB14MC11); also elsewhere on the board
!DS0: IC2.93 (P$93-FB16MC05); also elsewhere on the board
!DS1: IC2.78 (P$78-FB13MC17); also elsewhere on the board
!DTACK: IC2.85 (P$85-FB15MC12); also elsewhere on the board
!FCS: IC2.77 (P$77-FB13MC15); also elsewhere on the board
!LDS: IC2.82 (P$82-FB15MC10); also elsewhere on the board
!MTACK: IC2.96 (P$96-FB16MC10); also elsewhere on the board
!MTCR: IC2.101 (P$101-FB14MC05); also elsewhere on the board
!OVR: IC2.100 (P$100-FB14MC03); also elsewhere on the board
!OWN: IC2.107 (P$107-FB14MC15); also elsewhere on the board
!RESET: IC2.143 (P$143-FB6MC15/GSR); also elsewhere on the board
!SLAVE: IC2.106 (P$106-FB14MC14); also elsewhere on the board
!UDS: IC2.81 (P$81-FB15MC08); also elsewhere on the board
+3V3: C9.2, C10.2, C11.1, C12.1, C29.1, C30.2, C32.1, IC2.1 (P$1VCCIO), IC2.8 (P$8-VCCINT), IC2.37 (P$37-VCCIO), IC2.42 (P$42-VCCINT), IC2.55 (P$55-VCCIO), IC2.73 (P$73-VCCIO), IC2.84 (P$84-VCCINT), IC2.109 (P$109-VCCIO), IC2.127 (P$127-VCCIO), IC2.141 (P$141--VCCINT); also elsewhere on the board
+5V: RN1.5 (2), RN1.6 (2), RN1.7 (2), RN1.8 (2), SV2.4; also elsewhere on the board
A1: IC2.57 (P$57-FB9MC12); also elsewhere on the board
A2: IC2.54 (P$54-FB9MC08); also elsewhere on the board
A3: IC2.52 (P$52-FB9MC05); also elsewhere on the board
A4: IC2.50 (P$50-FB9MC02); also elsewhere on the board
A5: IC2.49 (P$49-FB7MC15); also elsewhere on the board
A6: IC2.51 (P$51-FB9MC03); also elsewhere on the board
A7: IC2.53 (P$53-FB9MC06); also elsewhere on the board
A8: IC2.56 (P$56-FB9MC11); also elsewhere on the board
A9: IC2.58 (P$58-FB9MC14); also elsewhere on the board
A10: IC2.59 (P$59-FB9MC17); also elsewhere on the board
A11: IC2.60 (P$60-FB11MC03); also elsewhere on the board
A12: IC2.61 (P$61-FB11MC05); also elsewhere on the board
A13: IC2.64 (P$64-FB11MC10); also elsewhere on the board
A14: IC2.66 (P$66-FB11MC11); also elsewhere on the board
A15: IC2.74 (P$74-FB13MC08); also elsewhere on the board
A16: IC2.97 (P$97-FB16MC11); also elsewhere on the board
A17: IC2.95 (P$95-FB16MC08); also elsewhere on the board
A18: IC2.94 (P$94-FB16MC06); also elsewhere on the board
A19: IC2.92 (P$92-FB16MC03); also elsewhere on the board
A20: IC2.91 (P$91-FB16MC02); also elsewhere on the board
A21: IC2.88 (P$88-FB15MC17); also elsewhere on the board
A22: IC2.87 (P$87-FB15MC15); also elsewhere on the board
A23: IC2.86 (P$86-FB15MC14); also elsewhere on the board
C1: IC2.103 (P$103-FB14MC08); also elsewhere on the board
C3: IC2.102 (P$102-FB14MC06); also elsewhere on the board
CLK_EXT: IC2.30 (P$30-FB3MC10/GCK1); also elsewhere on the board
CP_CS: IC2.34 (P$34-FB5MC02); also elsewhere on the board
CP_IRQ: IC2.31 (P$31-FB3MC12); also elsewhere on the board
CP_RD: IC2.71 (P$71-FB13MC02); also elsewhere on the board
CP_WE: IC2.70 (P$70-FB11MC17); also elsewhere on the board
C_IDE_A0: IC2.24 (P$24-FB1MC12); also elsewhere on the board
C_IDE_A1: IC2.26 (P$26-FB1MC15); also elsewhere on the board
C_IDE_A2: IC2.25 (P$25-FB1MC14); also elsewhere on the board
C_IDE_CS0: IC2.22 (P$22-FB1MC08); also elsewhere on the board
C_IDE_CS1: IC2.23 (P$23-FB1MC10); also elsewhere on the board
C_IDE_R: IC2.27 (P$27-FB1MC17); also elsewhere on the board
C_IDE_W: IC2.28 (P$28-FB3MC02); also elsewhere on the board
D0: IC2.2 (P$2-FB4MC02/GTS3); also elsewhere on the board
D1: IC2.17 (P$17-FB2MC15); also elsewhere on the board
D2: IC2.39 (P$39-FB5MC10); also elsewhere on the board
D3: IC2.15 (P$15-FB2MC12); also elsewhere on the board
D4: IC2.21 (P$21-FB1MC06); also elsewhere on the board
D5: IC2.20 (P$20-FB1MC05); also elsewhere on the board
D6: IC2.14 (P$14-FB2MC10); also elsewhere on the board
D7: IC2.16 (P$16-FB2MC14); also elsewhere on the board
D8: IC2.19 (P$19-FB2MC17); also elsewhere on the board
D9: IC2.40 (P$40-FB5MC12); also elsewhere on the board
D10: IC2.41 (P$41-FB5MC14); also elsewhere on the board
D11: IC2.43 (P$43-FB5MC15); also elsewhere on the board
D12: IC2.44 (P$44-FB5MC17); also elsewhere on the board
D13: IC2.45 (P$45-FB7MC03); also elsewhere on the board
D14: IC2.46 (P$46-FB7MC05); also elsewhere on the board
D15: IC2.48 (P$48-FB7MC12); also elsewhere on the board
DOE: IC2.38 (P$38-FB5MC08/GCK3); also elsewhere on the board
DQ0: IC2.118 (P$118-FB10MC03); also elsewhere on the board
DQ1: IC2.117 (P$117-FB10MC02); also elsewhere on the board
DQ2: IC2.120 (P$120-FB10MC06); also elsewhere on the board
DQ3: IC2.119 (P$119-FB10MC05); also elsewhere on the board
DQ4: IC2.124 (P$124-FB10MC10); also elsewhere on the board
DQ5: IC2.121 (P$121-FB10MC08); also elsewhere on the board
DQ6: IC2.126 (P$126-FB10MC12); also elsewhere on the board
DQ7: IC2.125 (P$125-FB10MC11); also elsewhere on the board
DQ8: IC2.128 (P$128-FB10MC14); also elsewhere on the board
DQ9: IC2.116 (P$116-FB12MC12); also elsewhere on the board
DQ10: IC2.129 (P$129-FB10MC17); also elsewhere on the board
DQ11: IC2.115 (P$115-FB12MC10); also elsewhere on the board
DQ12: IC2.130 (P$130-FB8MC02); also elsewhere on the board
DQ13: IC2.113 (P$113-FB12MC08); also elsewhere on the board
DQ14: IC2.131 (P$131-FB8MC03); also elsewhere on the board
DQ15: IC2.112 (P$112-FB12MC05); also elsewhere on the board
GND: C9.1, C10.1, C11.2, C12.2, C29.2, C30.1, C32.2, IC2.18 (P$18-GND), IC2.29 (P$29-GND), IC2.36 (P$36-GND), IC2.47 (P$47-GND), IC2.62 (P$62-GND), IC2.72 (P$72-GND), IC2.89 (P$89-GND), IC2.90 (P$90-GND), IC2.99 (P$99-GND), IC2.108 (P$108-GND), IC2.114 (P$114-GND), IC2.123 (P$123-GND), IC2.144 (P$144-GND), SV2.2, SV2.10; also elsewhere on the board
IDE_OFF: IC2.75 (P$75-FB13MC11); also elsewhere on the board
IDE_WAIT: IC2.33 (P$33-FB3MC15); also elsewhere on the board
INT2: IC2.32 (P$32-FB3MC14/GCK2); also elsewhere on the board
INT6: IC2.135 (P$135-FB6MC02); also elsewhere on the board
LAN_A0: IC2.4 (P$4-FB4MC06); also elsewhere on the board
LAN_A1: IC2.3 (P$3-FB4MC05/GTS4); also elsewhere on the board
LAN_A2: IC2.6 (P$6-FB4MC12/GTS2); also elsewhere on the board
LAN_A3: IC2.5 (P$5-FB4MC098/GTS1); also elsewhere on the board
LAN_A4: IC2.9 (P$9-FB2MC02); also elsewhere on the board
LAN_A5: IC2.7 (P$7-FB4MC14); also elsewhere on the board
LAN_A6: IC2.11 (P$11-FB2MC05); also elsewhere on the board
LAN_A7: IC2.10 (P$10-FB2MC03); also elsewhere on the board
LAN_A8: IC2.140 (P$140-FB6MC10); also elsewhere on the board
LAN_A9: IC2.142 (P$142-FB6MC14); also elsewhere on the board
LAN_A10: IC2.138 (P$138-FB6MC06); also elsewhere on the board
LAN_A11: IC2.139 (P$139-FB6MC08); also elsewhere on the board
LAN_A12: IC2.136 (P$136-FB6MC03); also elsewhere on the board
LAN_A13: IC2.137 (P$137-FB6MC05); also elsewhere on the board
LAN_CFG1: IC2.12 (P$12-FB2MC06)
LAN_CFG3: IC2.13 (P$13-FB2MC08)
LAN_CFG4: IC2.110 (P$110-FB12MC02)
LAN_CS: IC2.133 (P$133-FB8MC08); also elsewhere on the board
LAN_EN: IC2.76 (P$76-FB13MC14); also elsewhere on the board
LAN_INT: IC2.111 (P$111-FB12MC03); also elsewhere on the board
LAN_RD: IC2.134 (P$134-FB8MC10); also elsewhere on the board
LAN_WRH: IC2.132 (P$132-FB8MC05); also elsewhere on the board
unnamed: IC2.68 (P$68-FB11MC12), SJ1.1
R/W: IC2.83 (P$83-FB15MC11); also elsewhere on the board
ROM_B0: SJ1.2; also elsewhere on the board
ROM_B1: IC2.69 (P$69-FB11MC14); also elsewhere on the board
ROM_OE: IC2.35 (P$35-FB5MC05); also elsewhere on the board
TCK: IC2.67 (P$67-TCK), RN1.1, SV2.1
TDI: IC2.63 (P$63-TDI), RN1.3 (1), SV2.9
TDO: IC2.122 (P$122-TDO), SV2.3
TMS: IC2.65 (P$65-TMS), RN1.2 (1), SV2.5
Z3: IC2.79 (P$79-FB15MC02); also elsewhere on the board

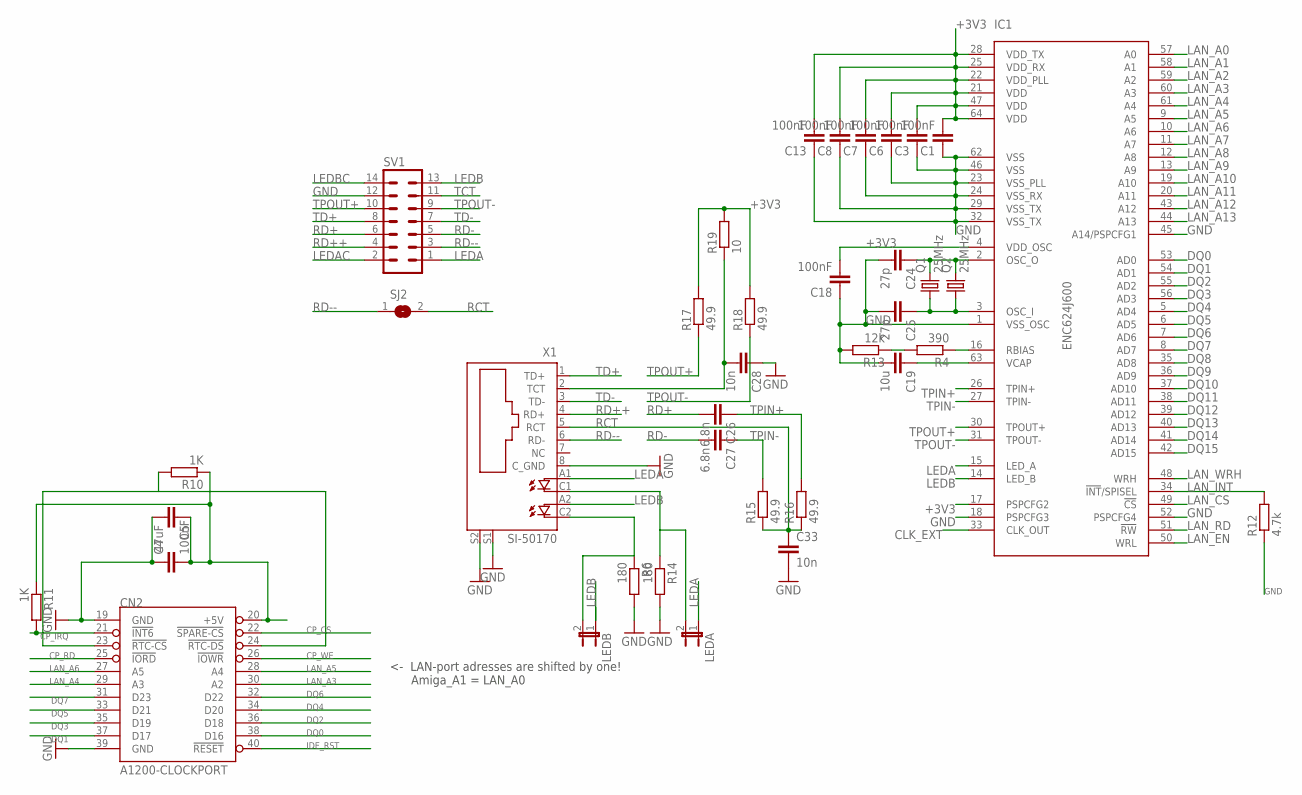
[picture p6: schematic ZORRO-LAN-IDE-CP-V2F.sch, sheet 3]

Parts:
C1, C3, C4, C6, C7, C8, C13, C18: 100nF; C0805K
C5: 47uF; C1206K
C19: 10u; C1206K
C24, C25: 27p; C0805K
C26, C27: 6.8n; C0805K
C28, C33: 10n; C0805K
CN2: A1200-CLOCKPORT; CP-2X11-2.00
IC1: ENC624J600; SQFP-S-10X10-64
LEDA: JP1E; JP1
LEDB: JP1E; JP1
Q1: 25MHz; HC18U-V
Q2: 25MHz; HC49UP
R4: 390; R0603
R6, R14: 180; R0603
R10, R11: 1K; R0805
R12: 4.7k; R0603
R13: 12k; R0603
R15, R16, R17, R18: 49.9; R0603
R19: 10; R0603
SJ2: SJ
SV1: ML14
X1: SI-50170

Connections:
+3V3: C1.2, C3.2, C6.2, C7.2, C8.2, C13.2, C18.2, IC1.4 (VDD_OSC), IC1.17 (PSPCFG2), IC1.21 (VDD), IC1.22 (VDD_PLL), IC1.25 (VDD_RX), IC1.28 (VDD_TX), IC1.47 (VDD), IC1.64 (VDD), R17.2, R18.2, R19.2; also elsewhere on the board
+5V: C4.2, C5.1, CN2.20 (+5V), R10.1, R11.1; also elsewhere on the board
CLK_EXT: IC1.33 (CLK_OUT); also elsewhere on the board
CP_CS: CN2.22 (!SPARE-CS); also elsewhere on the board
CP_IRQ: CN2.21 (!INT6), R11.2; also elsewhere on the board
CP_RD: CN2.25 (!IORD); also elsewhere on the board
CP_WE: CN2.26 (!IOWR); also elsewhere on the board
DQ0: CN2.38 (D16), IC1.53 (AD0); also elsewhere on the board
DQ1: CN2.37 (D17), IC1.54 (AD1); also elsewhere on the board
DQ2: CN2.36 (D18), IC1.55 (AD2); also elsewhere on the board
DQ3: CN2.35 (D19), IC1.56 (AD3); also elsewhere on the board
DQ4: CN2.34 (D20), IC1.5 (AD4); also elsewhere on the board
DQ5: CN2.33 (D21), IC1.6 (AD5); also elsewhere on the board
DQ6: CN2.32 (D22), IC1.7 (AD6); also elsewhere on the board
DQ7: CN2.31 (D23), IC1.8 (AD7); also elsewhere on the board
DQ8: IC1.35 (AD8); also elsewhere on the board
DQ9: IC1.36 (AD9); also elsewhere on the board
DQ10: IC1.37 (AD10); also elsewhere on the board
DQ11: IC1.38 (AD11); also elsewhere on the board
DQ12: IC1.39 (AD12); also elsewhere on the board
DQ13: IC1.40 (AD13); also elsewhere on the board
DQ14: IC1.41 (AD14); also elsewhere on the board
DQ15: IC1.42 (AD15); also elsewhere on the board
GND: C1.1, C3.1, C4.1, C5.2, C6.1, C7.1, C8.1, C13.1, C18.1, C19.2, C24.2, C25.2, C28.1, C33.2, CN2.19 (GND), CN2.39 (GND), IC1.1 (VSS_OSC), IC1.18 (PSPCFG3), IC1.23 (VSS_PLL), IC1.24 (VSS_RX), IC1.29 (VSS_TX), IC1.32 (VSS_TX), IC1.45 (A14/PSPCFG1), IC1.46 (VSS), IC1.52 (PSPCFG4), IC1.62 (VSS), R6.2, R12.1, R13.2, R14.2, SV1.12, X1.8 (C_GND), X1.S1, X1.S2; also elsewhere on the board
IDE_RST: CN2.40 (!RESET); also elsewhere on the board
LAN_A0: IC1.57 (A0); also elsewhere on the board
LAN_A1: IC1.58 (A1); also elsewhere on the board
LAN_A2: IC1.59 (A2); also elsewhere on the board
LAN_A3: CN2.30 (A2), IC1.60 (A3); also elsewhere on the board
LAN_A4: CN2.29 (A3), IC1.61 (A4); also elsewhere on the board
LAN_A5: CN2.28 (A4), IC1.9 (A5); also elsewhere on the board
LAN_A6: CN2.27 (A5), IC1.10 (A6); also elsewhere on the board
LAN_A7: IC1.11 (A7); also elsewhere on the board
LAN_A8: IC1.12 (A8); also elsewhere on the board
LAN_A9: IC1.13 (A9); also elsewhere on the board
LAN_A10: IC1.19 (A10); also elsewhere on the board
LAN_A11: IC1.20 (A11); also elsewhere on the board
LAN_A12: IC1.43 (A12); also elsewhere on the board
LAN_A13: IC1.44 (A13); also elsewhere on the board
LAN_CS: IC1.49 (!CS); also elsewhere on the board
LAN_EN: IC1.50 (WRL); also elsewhere on the board
LAN_INT: IC1.34 (!INT!/SPISEL), R12.2; also elsewhere on the board
LAN_RD: IC1.51 (!RW); also elsewhere on the board
LAN_WRH: IC1.48 (WRH); also elsewhere on the board
LEDA: IC1.15 (LED_A), LEDA.1, SV1.1, X1.A1 (A)
LEDAC: LEDA.2, R14.1, SV1.2, X1.C1 (C)
LEDB: IC1.14 (LED_B), LEDB.1, SV1.13, X1.A2 (A1)
LEDBC: LEDB.2, R6.1, SV1.14, X1.C2 (C1)
unnamed: CN2.23 (!RTC-CS), CN2.24 (!RTC-DS), R10.2
unnamed: C19.1, IC1.63 (VCAP)
unnamed: R4.2, R13.1
unnamed: IC1.16 (RBIAS), R4.1
unnamed: C25.1, IC1.3 (OSC_I), Q1.1, Q2.1
unnamed: C24.1, IC1.2 (OSC_O), Q1.2, Q2.2
RCT: C33.1, R15.1, R16.1, SJ2.2, X1.5 (RCT)
RD+: C26.2, SV1.6
RD++: SV1.4, X1.4 (RD+)
RD-: C27.2, SV1.5
RD--: SJ2.1, SV1.3, X1.6 (RD-)
TCT: C28.2, R19.1, SV1.11, X1.2 (TCT)
TD+: SV1.8, X1.1 (TD+)
TD-: SV1.7, X1.3 (TD-)
TPIN+: C26.1, IC1.26 (TPIN+), R16.2
TPIN-: C27.1, IC1.27 (TPIN-), R15.2
TPOUT+: IC1.30 (TPOUT+), R17.1, SV1.10
TPOUT-: IC1.31 (TPOUT-), R18.1, SV1.9

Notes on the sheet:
<- LAN-port adresses are shifted by one! Amiga_A1 = LAN_A0

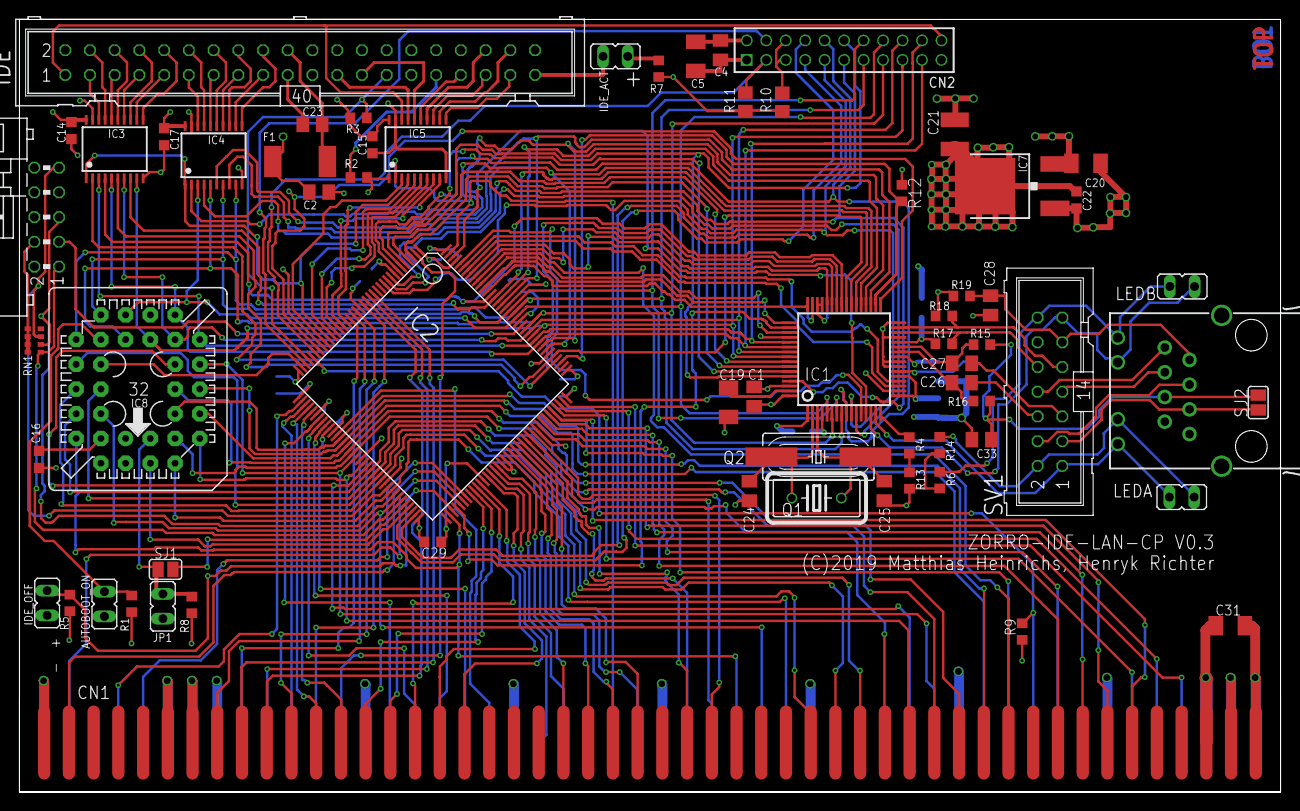
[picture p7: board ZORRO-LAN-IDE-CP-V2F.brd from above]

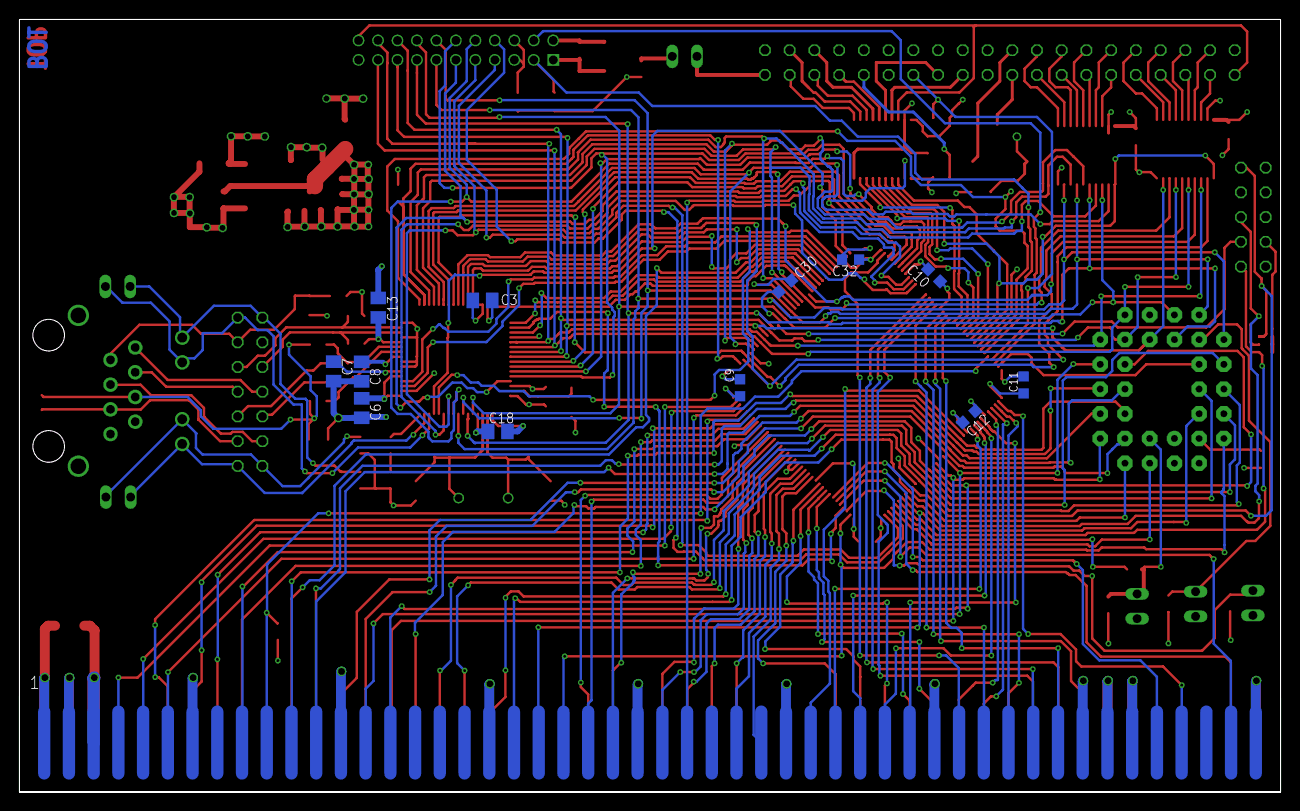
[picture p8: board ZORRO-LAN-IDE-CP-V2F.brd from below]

Board: 4 copper layers, 129.5 x 79.4 mm, 77 parts (12 on the bottom side), 173 nets.

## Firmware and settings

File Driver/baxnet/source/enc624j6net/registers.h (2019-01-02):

/*  ------------------------------------------------------------------------------ */
/*  | Lowlevel Access to memory mapped ENC624J600 in PSP mode                    | */
/*  | Henryk Richter <henryk.richter@gmx.net>                                    | */
/*  ------------------------------------------------------------------------------ */
/*  register definition section */
#ifndef _REGISTERS_H_
#define _REGISTERS_H_

/*  set/clr register offsets */
#define SET_OFFSET 0x0100
#define CLR_OFFSET 0x0180

/*  Register definitions */

/*  SPI Bank 0 registers -------- */
#define ETXST	    0x7E00
#define ETXSTL	    0x7E00
#define ETXSTH	    0x7E01
#define ETXLEN	    0x7E02
#define ETXLENL	    0x7E02
#define ETXLENH	    0x7E03
#define ERXST	    0x7E04
#define ERXSTL	    0x7E04
#define ERXSTH	    0x7E05
#define ERXTAIL	    0x7E06
#define ERXTAILL    0x7E06
#define ERXTAILH    0x7E07
#define ERXHEAD	    0x7E08
#define ERXHEADL    0x7E08
#define ERXHEADH    0x7E09
#define EDMAST	    0x7E0A
#define EDMASTL	    0x7E0A
#define EDMASTH	    0x7E0B
#define EDMALEN	    0x7E0C
#define EDMALENL    0x7E0C
#define EDMALENH    0x7E0D
#define EDMADST	    0x7E0E
#define EDMADSTL    0x7E0E
#define EDMADSTH    0x7E0F
#define EDMACS	    0x7E10
#define EDMACSL	    0x7E10
#define EDMACSH	    0x7E11
#define ETXSTAT	    0x7E12
#define ETXSTATL    0x7E12
#define ETXSTATH    0x7E13
#define ETXWIRE	    0x7E14
#define ETXWIREL    0x7E14
#define ETXWIREH    0x7E15

/*  SPI all bank registers */
#define EUDAST	    0x7E16
#define EUDASTL	    0x7E16
#define EUDASTH	    0x7E17
#define EUDAND	    0x7E18
#define EUDANDL	    0x7E18
#define EUDANDH	    0x7E19
#define ESTAT	    0x7E1A
#define ESTATL	    0x7E1A
#define ESTATH	    0x7E1B
#define EIR	    0x7E1C
#define EIRL	    0x7E1C
#define EIRH	    0x7E1D
#define ECON1	    0x7E1E
#define ECON1L	    0x7E1E
#define ECON1H	    0x7E1F


/*  SPI Bank 1 registers ----- */
#define EHT1	    0x7E20
#define EHT1L	    0x7E20
#define EHT1H	    0x7E21
#define EHT2	    0x7E22
#define EHT2L	    0x7E22
#define EHT2H	    0x7E23
#define EHT3	    0x7E24
#define EHT3L	    0x7E24
#define EHT3H	    0x7E25
#define EHT4	    0x7E26
#define EHT4L	    0x7E26
#define EHT4H	    0x7E27
#define EPMM1	    0x7E28
#define EPMM1L	    0x7E28
#define EPMM1H	    0x7E29
#define EPMM2	    0x7E2A
#define EPMM2L	    0x7E2A
#define EPMM2H	    0x7E2B
#define EPMM3	    0x7E2C
#define EPMM3L	    0x7E2C
#define EPMM3H	    0x7E2D
#define EPMM4	    0x7E2E
#define EPMM4L	    0x7E2E
#define EPMM4H	    0x7E2F
#define EPMCS	    0x7E30
#define EPMCSL	    0x7E30
#define EPMCSH	    0x7E31
#define EPMO	    0x7E32
#define EPMOL	    0x7E32
#define EPMOH	    0x7E33
#define ERXFCON	    0x7E34
#define ERXFCONL    0x7E34
#define ERXFCONH    0x7E35

/*  SPI all bank registers from 0x36 to 0x3F */
/*  SPI Bank 2 registers ----- */
#define MACON1	    0x7E40
#define MACON1L	    0x7E40
#define MACON1H	    0x7E41
#define MACON2	    0x7E42
#define MACON2L	    0x7E42
#define MACON2H	    0x7E43
#define MABBIPG	    0x7E44
#define MABBIPGL    0x7E44
#define MABBIPGH    0x7E45
#define MAIPG	    0x7E46
#define MAIPGL	    0x7E46
#define MAIPGH	    0x7E47
#define MACLCON	    0x7E48
#define MACLCONL    0x7E48
#define MACLCONH    0x7E49
#define MAMXFL	    0x7E4A
#define MAMXFLL	    0x7E4A
#define MAMXFLH	    0x7E4B
#define MICMD	    0x7E52
#define MICMDL	    0x7E52
#define MICMDH	    0x7E53
#define MIREGADR    0x7E54
#define MIREGADRL    0x7E54
#define MIREGADRH    0x7E55

/*  SPI all bank registers from 0x56 to 0x5F */
/*  SPI Bank 3 registers ----- */
#define MAADR3	    0x7E60
#define MAADR3L	    0x7E60
#define MAADR3H	    0x7E61
#define MAADR2	    0x7E62
#define MAADR2L	    0x7E62
#define MAADR2H	    0x7E63
#define MAADR1	    0x7E64
#define MAADR1L	    0x7E64
#define MAADR1H	    0x7E65
#define MIWR	    0x7E66
#define MIWRL	    0x7E66
#define MIWRH	    0x7E67
#define MIRD	    0x7E68
#define MIRDL	    0x7E68
#define MIRDH	    0x7E69
#define MISTAT	    0x7E6A
#define MISTATL	    0x7E6A
#define MISTATH	    0x7E6B
#define EPAUS	    0x7E6C
#define EPAUSL	    0x7E6C
#define EPAUSH	    0x7E6D
#define ECON2	    0x7E6E
#define ECON2L	    0x7E6E
#define ECON2H	    0x7E6F
#define ERXWM	    0x7E70
#define ERXWML	    0x7E70
#define ERXWMH	    0x7E71
#define EIE	    0x7E72
#define EIEL	    0x7E72
#define EIEH	    0x7E73
#define EIDLED	    0x7E74
#define EIDLEDL	    0x7E74
#define EIDLEDH	    0x7E75

/*  SPI all bank registers from 0x66 to 0x6F */

/*  SPI Non-banked Special Function Registers */
#define EGPDATA	    0x7E80
#define EGPDATAL    0x7E80
#define ERXDATA	    0x7E82
#define ERXDATAL    0x7E82
#define EUDADATA    0x7E84
#define EUDADATAL    0x7E84
#define EGPRDPT	    0x7E86
#define EGPRDPTL    0x7E86
#define EGPRDPTH    0x7E87
#define EGPWRPT	    0x7E88
#define EGPWRPTL    0x7E88
#define EGPWRPTH    0x7E89
#define ERXRDPT	    0x7E8A
#define ERXRDPTL    0x7E8A
#define ERXRDPTH    0x7E8B
#define ERXWRPT	    0x7E8C
#define ERXWRPTL    0x7E8C
#define ERXWRPTH    0x7E8D
#define EUDARDPT    0x7E8E
#define EUDARDPTL    0x7E8E
#define EUDARDPTH    0x7E8F
#define EUDAWRPT    0x7E90
#define EUDAWRPTL    0x7E90
#define EUDAWRPTH    0x7E91

/* ;;;;;;;;;;;;;;;;;;;;;;;;; */
/*  ENC424J600/624J600 register bits */
/* ;;;;;;;;;;;;;;;;;;;;;;;;; */
/*  ESTAT bits ---------- */
#define ESTAT_INT	    (1<<15)
#define ESTAT_FCIDLE    (1<<14)
#define ESTAT_RXBUSY    (1<<13)
#define ESTAT_CLKRDY    (1<<12)
#define ESTAT_RSTDONE    (1<<11)
#define ESTAT_PHYDPX    (1<<10)
#define ESTAT_PHYRDY    (1<<9)
#define ESTAT_PHYLNK    (1<<8)
#define ESTAT_PKTCNT7    (1<<7)
#define ESTAT_PKTCNT6    (1<<6)
#define ESTAT_PKTCNT5    (1<<5)
#define ESTAT_PKTCNT4    (1<<4)
#define ESTAT_PKTCNT3    (1<<3)
#define ESTAT_PKTCNT2    (1<<2)
#define ESTAT_PKTCNT1    (1<<1)
#define ESTAT_PKTCNT0    (1)

/*  EIR bits ------------ */
#define EIR_CRYPTEN	    (1<<15)
#define EIR_MODEXIF	    (1<<14)
#define EIR_HASHIF	    (1<<13)
#define EIR_AESIF	    (1<<12)
#define EIR_LINKIF	    (1<<11)
#define EIR_PRDYIF	    (1<<10)
#define EIR_r9		    (1<<9)
#define EIR_r8		    (1<<8)
#define EIR_r7		    (1<<7)
#define EIR_PKTIF	    (1<<6)
#define EIR_DMAIF	    (1<<5)
#define EIR_r4		    (1<<4)
#define EIR_TXIF	    (1<<3)
#define EIR_TXABTIF	    (1<<2)
#define EIR_RXABTIF	    (1<<1)
#define EIR_PCFULIF	    (1)

/*  ECON1 bits ---------- */
#define ECON1_MODEXST    (1<<15)
#define ECON1_HASHEN    (1<<14)
#define ECON1_HASHOP    (1<<13)
#define ECON1_HASHLST    (1<<12)
#define ECON1_AESST	    (1<<11)
#define ECON1_AESOP1    (1<<10)
#define ECON1_AESOP0    (1<<9)
#define ECON1_PKTDEC    (1<<8)
#define ECON1_FCOP1	    (1<<7)
#define ECON1_FCOP0	    (1<<6)
#define ECON1_DMAST	    (1<<5)
#define ECON1_DMACPY    (1<<4)
#define ECON1_DMACSSD    (1<<3)
#define ECON1_DMANOCS    (1<<2)
#define ECON1_TXRTS	    (1<<1)
#define ECON1_RXEN	    (1)
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

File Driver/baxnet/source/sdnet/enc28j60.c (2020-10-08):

/*
 Microchip ENC28J60 Ethernet Interface Driver
 Author: Henryk Richter
 Copyright: GPL V2

 Notes: when I ran into timing issues in early development, I moved over to quickly
        testable ASM code for SPI communication. I didn't bother porting that stuff
	back into C code. So this file now references enc28j60l.asm for lowlevel direct 
	hardware access.
	As a consequence, the only functions needed from spi.c are the spi_init() and
	spi_disable_eth().

 TODO:  - support for power down when unused, i.e. offline
        - replace busy waiting loop after reset

 Based on work by
  Christian Vogelgsaang
  Guido Socher
  Pascal Stang (see enc28j60.c in AVRlib library for the original file)
*/
#undef _DO_DUMP

/* used for Delay() */
#include <dos/dos.h>
#include <proto/dos.h>

#ifdef _DO_DUMP
#include <stdio.h>
#endif

#include "compiler.h"
#include "enc28j60.h"
#include "enc28j60l.h" /* import lowlevel asm functions */
/* #include "spi.h" */ /* no direct use anymore, just for init purposes) */
#include "device.h"

/*
  The RXSTART_INIT must be zero. See Rev. B4 Silicon Errata point 5.
  Buffer boundaries applied to internal 8K ram
  the entire available packet buffer space is allocated

  rx packet layout
  6 byte heaader
  1518 
  sum: 1524
*/

#define RXSTART_INIT        0x0000  /*  start of RX buffer, room for 4 packets */
#define RXSTOP_INIT         0x19FF  /*  end of RX buffer */
                            
#define TXSTART_INIT        0x1A00  /*  start of TX buffer, room for 1 packet */
#define TXSTOP_INIT         0x1FFF  /*  end of TX buffer */
                            
/*  max frame length which the conroller will accept: */
/*  (note: maximum ethernet frame length would be 1518 when VLAN tagging is unused) */
#define MAX_FRAMELEN      1518 

/* perform sanity checks if more this amount of "idle" calls to have_recv()
   are noted (idle=nothing received)
*/
#define SANITY_CHECK_INTERVAL	32

static u16 gNextPacketPtr;
static u08 is_full_duplex;
static u08 rev;

struct enc28j60_initvars {
	u16	have_recv;
	u08	last_mac[6];
	u08	macon1;
	u08	macon2;
	u08	macon3;
	u08	macon4;
};
static struct enc28j60_initvars initvars;


static void enc28j60_recv_reset( struct enc28j60_initvars *iv, u08 restart );
static int  enc28j60_check_config( struct enc28j60_initvars *iv );


static uint8_t readOp (uint8_t op, uint8_t address) 
{
 return enc28j60l_ReadOp( op, address );
}

static void writeOp (uint8_t op, uint8_t address, uint8_t data)
{
    enc28j60l_WriteOp( op, address,data );
}

static void readBuf(uint16_t len, uint8_t* data)
{
    enc28j60l_ReadBuffer( data, (unsigned int)len ); 
}

void SetBank (uint8_t address)
{
 enc28j60l_SetBank(address);
}

static uint8_t readRegByte (uint8_t address)
{
 return enc28j60l_ReadRegByte( address );
}

#if 0
static uint16_t readReg(uint8_t address) {
	return readRegByte(address) + (readRegByte(address+1) << 8);
}
#endif

static void writeRegByte (uint8_t address, uint8_t data)
{
 enc28j60l_WriteRegByte( address, data );
}

static void writeReg(uint8_t address, uint16_t data)
{
 enc28j60l_WriteReg( address, data );
}

/*
  the PHY registers require special care
*/
static uint16_t readPhyByte (uint8_t address) 
{
    long wtime = 0xffff;
    
    writeRegByte(MIREGADR, address);
    writeRegByte(MICMD, MICMD_MIIRD);
    while (readRegByte(MISTAT) & MISTAT_BUSY)
    {
	if( (--wtime) <= 0 )
	{
		writeRegByte(MICMD, 0x00);
		initvars.have_recv = SANITY_CHECK_INTERVAL+1;
		return 0xffff;
	}
    }
    writeRegByte(MICMD, 0x00);
    return readRegByte(MIRD+1);
}

static void writePhy (uint8_t address, uint16_t data)
{
    long wtime = 0xffff;

    writeRegByte(MIREGADR, address);
    writeReg(MIWR, data);
    while (readRegByte(MISTAT) & MISTAT_BUSY)
    {
	if( (--wtime) <= 0 )
	{
		initvars.have_recv = SANITY_CHECK_INTERVAL+1;
		break;
	}
    }
}

/* just a pass-through to the lowlevel routines */
void enc28j60_SetSPISpeed( unsigned long clock_divider )
{
	enc28j60l_SetSPISpeed( clock_divider );
}

/*  ---------- init ---------- */

/*  Functions to enable/disable broadcast filter bits */
/*  With the bit set, broadcast packets are filtered. */
void enc28j60_broadcast_multicast_filter( u08 flags  )
{
	u08 val = ERXFCON_UCEN|ERXFCON_CRCEN; /* default: crc check and unicast */

	if( flags & PIO_INIT_PROMISC )
	{
		val = 0;
	}
	else
	{
		if( flags & PIO_INIT_BROAD_CAST )
			val |= ERXFCON_BCEN;
		if( flags & PIO_INIT_MULTI_CAST )
			val |= ERXFCON_MCEN;
	}
	writeRegByte(ERXFCON, val );
}

static void enc28j60_recv_reset( struct enc28j60_initvars *iv, u08 restart )
{
	writeOp(ENC28J60_BIT_FIELD_CLR, ECON1, ECON1_RXEN);
	writeOp(ENC28J60_BIT_FIELD_SET, ECON1, ECON1_RXRST);
	writeOp(ENC28J60_BIT_FIELD_CLR, ECON1, ECON1_RXRST);
	writeOp(ENC28J60_BIT_FIELD_CLR, ESTAT, ESTAT_TXABRT);

	gNextPacketPtr = RXSTART_INIT;
	writeReg(ERXST,   RXSTART_INIT);
	writeReg(ERXRDPT, RXSTOP_INIT );
	writeReg(ERXND,   RXSTOP_INIT);
	writeOp(ENC28J60_BIT_FIELD_CLR, EIR, EIR_TXERIF|EIR_RXERIF );
	writeReg(MAMXFL, MAX_FRAMELEN);

	writeRegByte(MACON4, iv->macon4 ); /* DEFER bit */
	writeRegByte(MACON3, iv->macon3 );
	writeRegByte(MACON2, iv->macon2 );
	writeRegByte(MACON1, iv->macon1 );

	enc28j60_setMAC( iv->last_mac );

	writePhy(PHIE, PHIE_PGEIE|PHIE_LNKIE );
 	writePhy(PHLCON, 0x3c12 ); /* 3(fixed) C(LinkStat+RX Act) 1(TX Act) 2(Stretch enable) */
 
	/*  prepare flow control */
	writeReg(EPAUS, 20 * 100); /*  100ms */

	if( restart )
		writeOp(ENC28J60_BIT_FIELD_SET, ECON1, ECON1_RXEN);

	iv->have_recv = 0;
}


static int  enc28j60_check_config( struct enc28j60_initvars *iv )
{
	int	ret = 1;	/* def: be optimistic */

	/* check RX registers */
	if( !(readOp(ENC28J60_READ_CTRL_REG, ECON1) & ECON1_RXEN ) )
		ret = 0;
	if( (readRegByte(MACON1)&iv->macon1) != iv->macon1 )
		ret = 0;
	if( (readRegByte(MACON2)&iv->macon2) != iv->macon2 )
		ret = 0;
	if( (readRegByte(MACON3)&iv->macon3) != iv->macon3 )
		ret = 0;

	/* check TX problems */
	if( readRegByte(ESTAT) & ESTAT_TXABRT )
		ret = 0;
	if( readRegByte(EIR) & EIR_TXERIF )
		ret = 0;

	/* Verify MAC */
	if( readRegByte(MAADR5) != iv->last_mac[0] )
		ret = 0;
	if( readRegByte(MAADR4) != iv->last_mac[1] )
		ret = 0;
	if( readRegByte(MAADR3) != iv->last_mac[2] )
		ret = 0;
	if( readRegByte(MAADR2) != iv->last_mac[3] )
		ret = 0;
	if( readRegByte(MAADR1) != iv->last_mac[4] )
		ret = 0;
	if( readRegByte(MAADR0) != iv->last_mac[5] )
		ret = 0;

	return	ret;
}




u08 enc28j60_init(const u08 macaddr[6], u08 flags)
{
  unsigned int count;
  u08 mac3val;
  struct enc28j60_initvars *iv = &initvars;

  enc28j60l_Init(); /*  spi_init(); spi_disable_eth(); */

  {
	int i;
	for(i=0 ; i < 6 ; i++ )
		iv->last_mac[i] = macaddr[i];
  }

  is_full_duplex = (flags & PIO_INIT_FULL_DUPLEX) == PIO_INIT_FULL_DUPLEX;

  /*  soft reset cpu */
  writeOp(ENC28J60_SOFT_RESET, 0, ENC28J60_SOFT_RESET);
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

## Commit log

2018-06-09 Working on Rev2
    [ZORRO-LAN-IDE-CP-V2.brd, ZORRO-LAN-IDE-CP-V2.sch]
2018-06-09 Switched Driver to baxnet-structure
    [LAN_IDE_CP_pad.csv]
2018-06-14 Updated LAN driver - changed directory layout - Multicast support (automatic RX filter adjustment) - MC68000 target in Makefile - clarified licensing (GPLv3) - README files
2018-11-26 Auto stash before merge of "master" and "origin/driverupdate"
2018-12-14 z3 ac is working
    [LAN_IDE_CP_pad.csv]
2018-12-17 sm cleaned up
    [LAN_IDE_CP_pad.csv]
2018-12-17 Datata access works for fixed base address
    [LAN_IDE_CP_pad.csv]
2018-12-17 Byteswap working
    [LAN_IDE_CP_pad.csv]
2018-12-18 AC working and swapping disabled
    use fit.bat 54 35
    [LAN_IDE_CP_pad.csv]
2018-12-18 Swapping enabled but freeze lock during driver
    [LAN_IDE_CP_pad.csv]
2018-12-18 Set driver init to 25MHz
    [LAN_IDE_CP_pad.csv]
2018-12-18 Busspeed tweaked: 6-7MB/s Zorro3-Speed
    [LAN_IDE_CP_pad.csv]
2018-12-19 Added new PCB-Layout
    Fixed CP-Address bug and added limit for via-mask
    [ZORRO-LAN-IDE-CP-V2D.brd, ZORRO-LAN-IDE-CP-V2D.sch, ZORRO-LAN-IDE-CP-V2DFront.brd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]
2018-12-19 Gerbers added and Front enlarged
    [ZORRO-LAN-IDE-CP-V2DFront.brd]
2018-12-19 Cacheinhibit must be asserted!
    [LAN_IDE_CP_pad.csv]
2018-12-19 No swap of upper/lower word
    [LAN_IDE_CP_pad.csv]
2018-12-19 New compile with 25MHz
    [LAN_IDE_CP_pad.csv]
2019-01-01 before rollback to z2 to find the databus bug
    [LAN_IDE_CP_pad.csv]
2019-01-02 Working! Use "fit.bat 54 35"
    [LAN_IDE_CP_pad.csv]
2019-01-02 Start of reintegration IDE/CP AutoConfig works
    [LAN_IDE_CP_pad.csv]
2019-01-02 IDE and CP working in z2-mode
    [LAN_IDE_CP_pad.csv]
2019-01-02 New driver
2019-01-06 Clean up and driver update
    [ZORRO-LAN-IDE-CP-V2.brd, ZORRO-LAN-IDE-CP-V2.sch, ZORRO-LAN-IDE-CP-V2D.brd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]
2019-02-19 Update in Firmware (pure Z2-AC but LAN becomes Z3) and new pcb
    [LAN_IDE_CP_pad.csv, ZORRO-LAN-IDE-CP-V2F.brd, ZORRO-LAN-IDE-CP-V2F.sch]
2019-02-20 CP working in Z3 and driver update
    A fix for int6 is needed for the first proto: Connect SJ1 right with INT6-Pad. But CP and lan are not working with AmiTCP
    [LAN_IDE_CP_pad.csv]
2019-02-21 Z2-Firmware with working CP and LAN
    [LAN_IDE_CP_pad.csv]
2019-02-21 Z3-LAN working and cp working but not together
    [LAN_IDE_CP_pad.csv]
2019-02-26 try for CP in Z3
    [LAN_IDE_CP_pad.csv]
2019-02-27 fully clocked z3-statemachine for lan without reset-hack
    [LAN_IDE_CP_pad.csv]
2019-02-28 toggle-edge-detection for fcs
    [LAN_IDE_CP_pad.csv]
2019-03-07 CP and LAN working! Clockport needed to be stopped if FCS='1'
    [LAN_IDE_CP_pad.csv]
2019-03-19 V2 changes: - moved IRQ6 to Pin 135 in pinlist and VHD files - added IDE data lines to Z3 vhd
2019-03-20 updated LAN driver
2019-03-20 new jed files for V2 board, untested for now
2019-04-13 updated ENC624j6net driver - fixes to gcc native and cross compilation settings - implemented hardware based multicast filtering hashes, resulting in less unwanted traffic to our Amigas (especially B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
    [hw.c]
2019-05-26 Firmware for new version. IDE and CP working
    [ZORRO-LAN-IDE-CP-V2F.brd, ZORRO-LAN-IDE-CP-V2F.sch]
2019-06-06 driver update - fixed gcc cross compilation linker woes by using aout instead of hunk for asm files - temporarily reverted to full ENC chip resets on initialization
    [hw.h]
2019-06-06 misc. updates - added device.i in preparation of moving some operation sequences closer to the hardware implementation, if desired - added picture of V3 card
2019-06-11 LAN driver update - separate semaphore for write queue (about 2% more speed) - re-enabled init optimization (avoidance of full chip resets, still experimental)
    [hw.c]
2019-11-14 Updated baxnet-driver ansd Z3-Interface
    [LAN_IDE_CP_pad.csv]
2020-02-14 updated baxnet SANA-II driver and Gerber files - Enforcer hit fix - replaced V2 Gerbers by V3 Gerbers
    [enc28j60.c, hw.c, hw.h]
2020-05-03 Driver - updated miitool binary
2020-06-23 updated network driver to v2.8 with fixes related to Fusion
2020-08-24 Driver updated to version 2.9 Changes: better Envoy support
2020-10-08 Improved clock startup and IDE-ROM-timing
    [ZORRO-LAN-IDE-CP-V2F.brd, ZORRO-LAN-IDE-CP-V2F.sch]

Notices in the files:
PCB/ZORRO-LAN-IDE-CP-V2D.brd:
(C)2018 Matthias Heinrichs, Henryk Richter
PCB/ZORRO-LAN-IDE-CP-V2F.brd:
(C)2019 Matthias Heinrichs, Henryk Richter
